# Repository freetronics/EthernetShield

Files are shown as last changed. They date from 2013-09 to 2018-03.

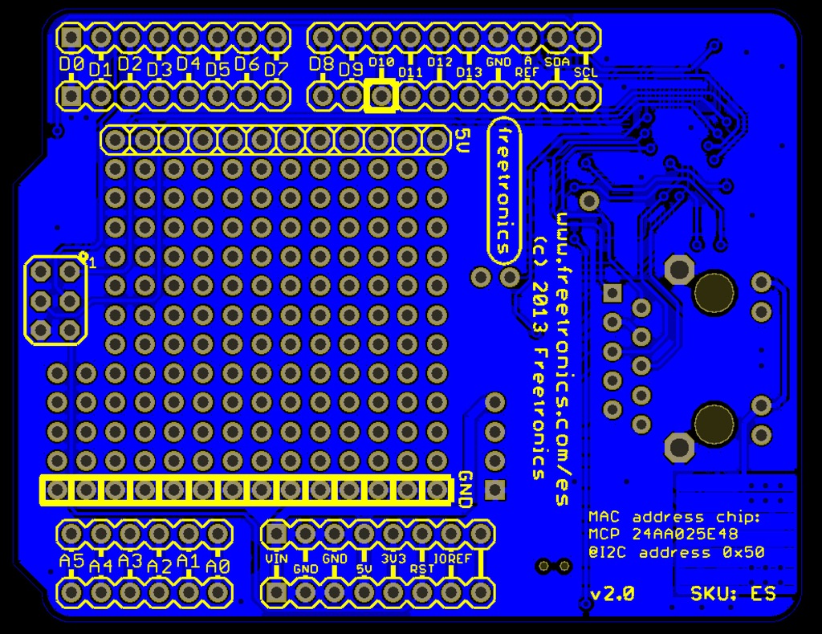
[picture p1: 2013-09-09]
docs/EthernetShield-pcb-bottom.jpg

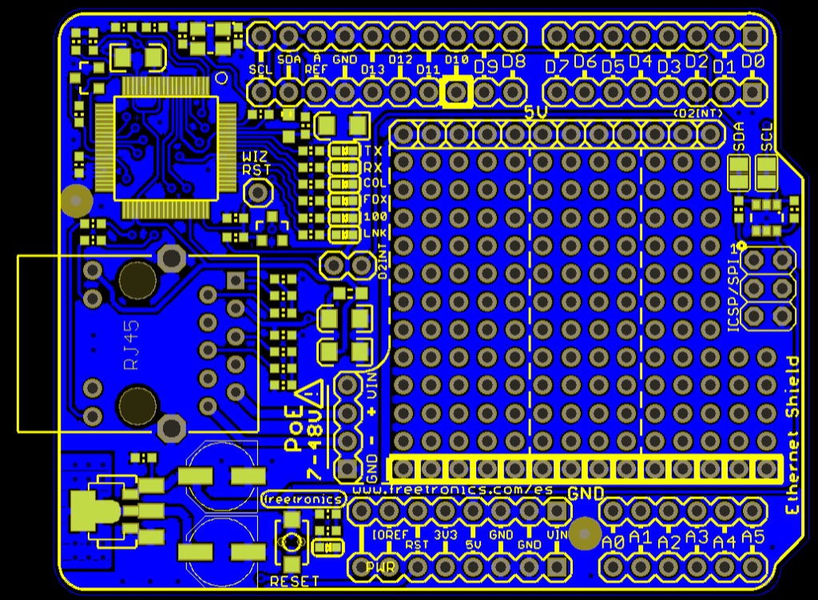
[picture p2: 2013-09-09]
docs/EthernetShield-pcb-top.jpg

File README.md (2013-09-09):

Freetronics Ethernet Shield
===========================
Copyright 2010-2012 Freetronics Pty Ltd  
Freetronics site:  www.freetronics.com  
Freetronics email: info@freetronics.com  

10/100base-T Ethernet shield for the Freetronics Eleven, Arduino Uno,
and other boards compatible with the R3 header format.

Includes significant prototyping area using the spare shield area, and
supports Power-over-Ethernet (PoE) using either simple jumpers for DIY
PoE or a daughter-board module for full standards-compliant PoE.

Features:

 * Prototyping area.
 * 10/100Base-T connectivity.
 * Power-over-Ethernet "PD" (powered device) support.
 * Activity / status indicators.
 * Reset button wired through to Arduino reset pin.
 * Wiznet W5100 IC reset circuit.
 * SPI bus contention fixed for W5100 IC.
 * Parts overlay on both the top and the bottom.

More information is available on our product page at:

  http://www.freetronics.com/ethernet

The "docs" folder within this repository includes a handy copy of the
schematic in PDF format and image(s) of the pcb.

INSTALLATION
------------
The design is saved as an EAGLE project. EAGLE PCB design software is
available from www.cadsoftusa.com free for non-commercial use. To use
this project download it and place the directory containing these files
into the "eagle" directory on your computer. Then open EAGLE and
navigate to Projects -> eagle -> EthernetShieldR3.

DISTRIBUTION
------------
The specific terms of distribution of this project are governed by the
license referenced below.

LICENSE
-------
Licensed under the TAPR Open Hardware License (www.tapr.org/OHL).
The "license" folder within this repository also contains a copy of
this license in plain text format.

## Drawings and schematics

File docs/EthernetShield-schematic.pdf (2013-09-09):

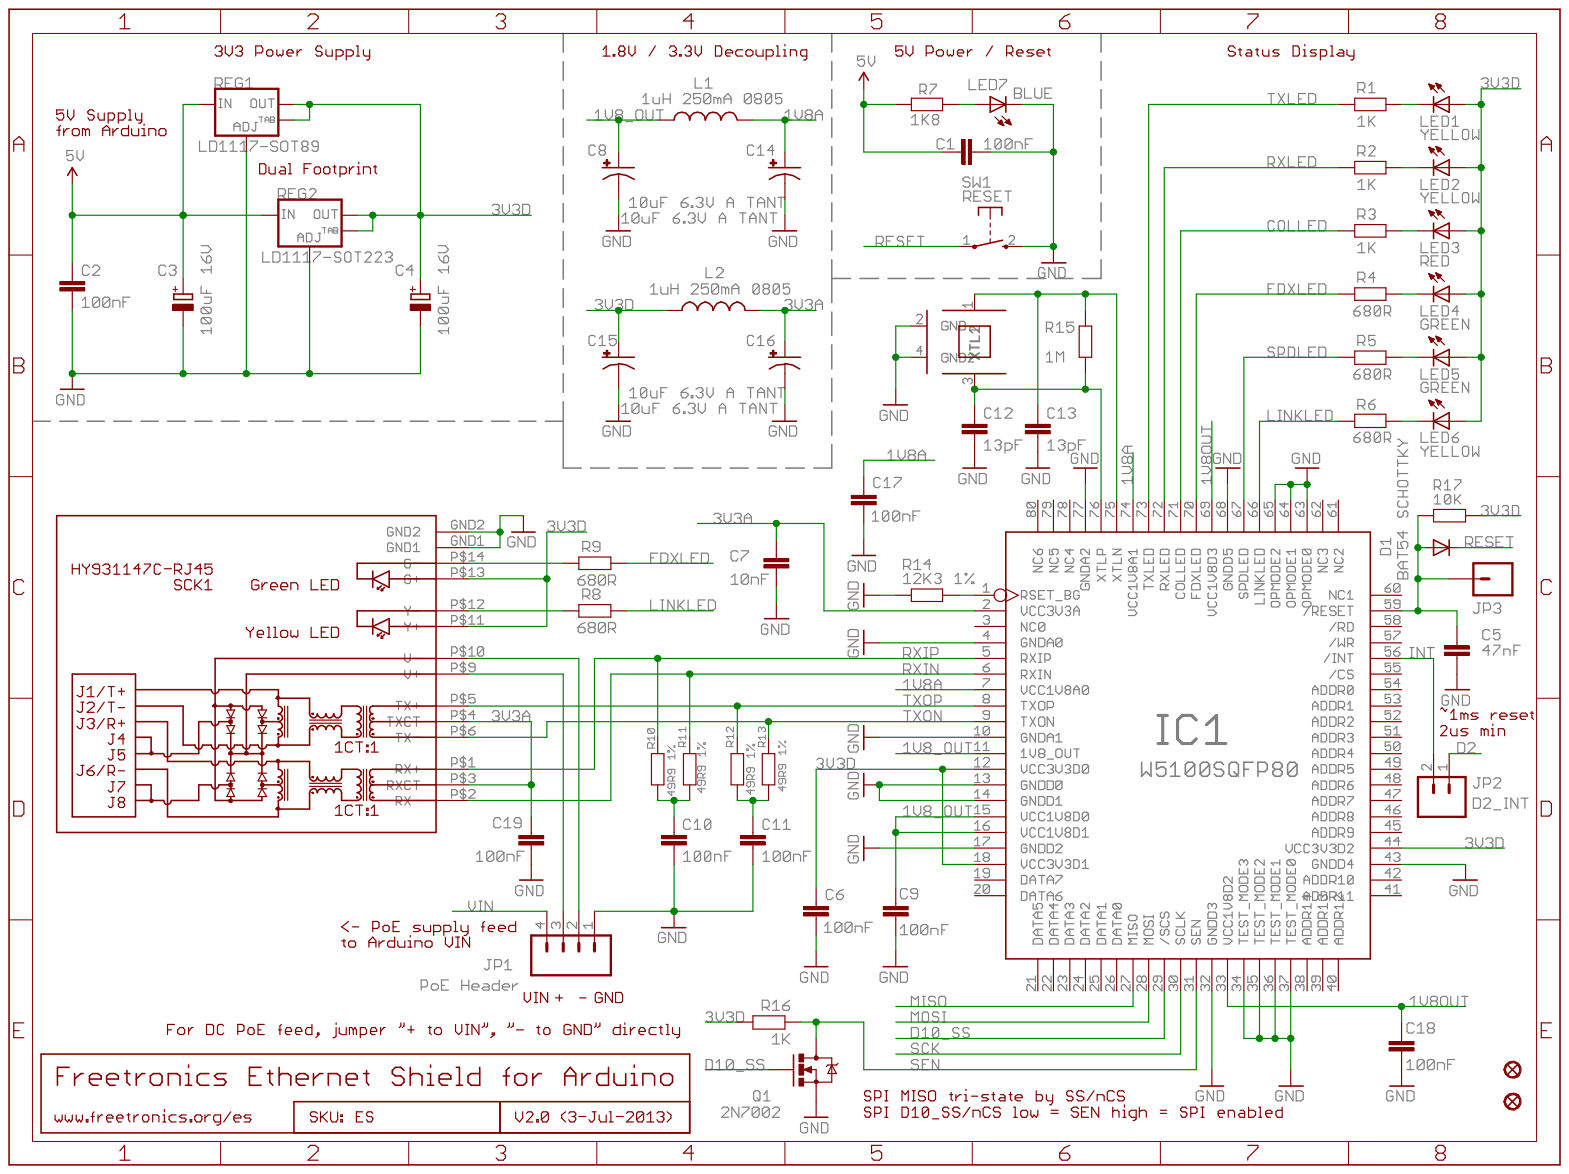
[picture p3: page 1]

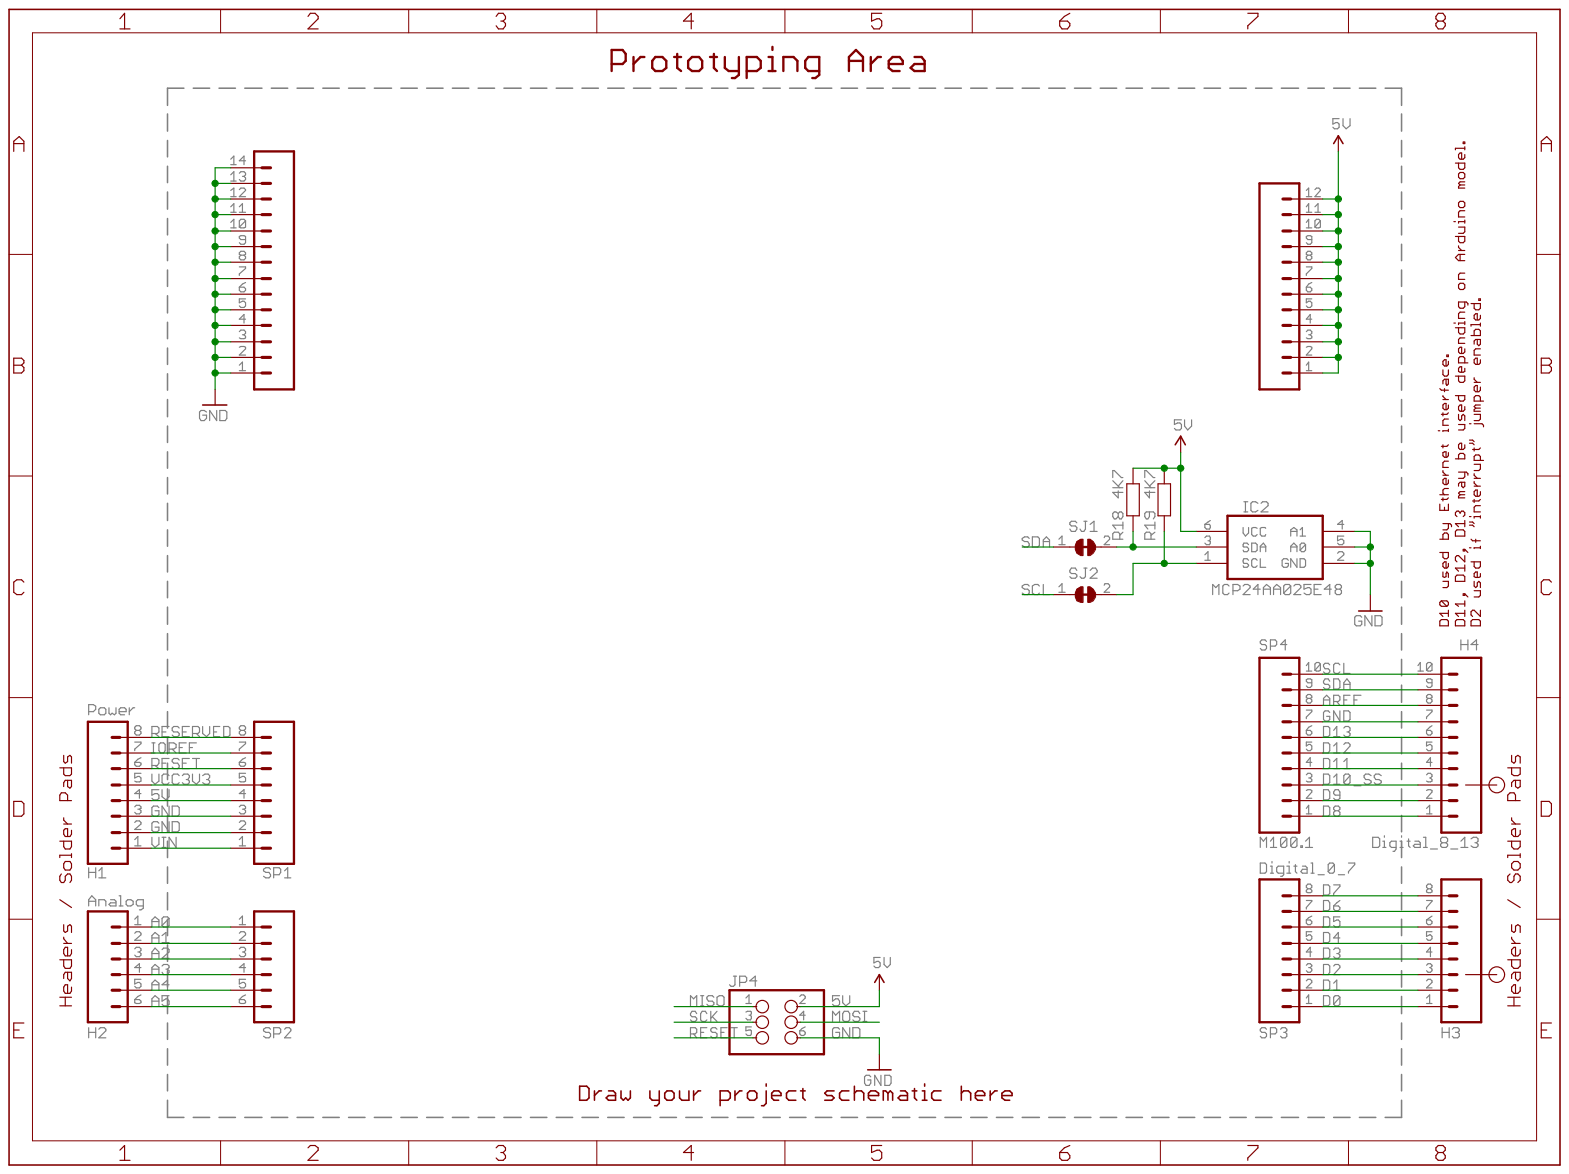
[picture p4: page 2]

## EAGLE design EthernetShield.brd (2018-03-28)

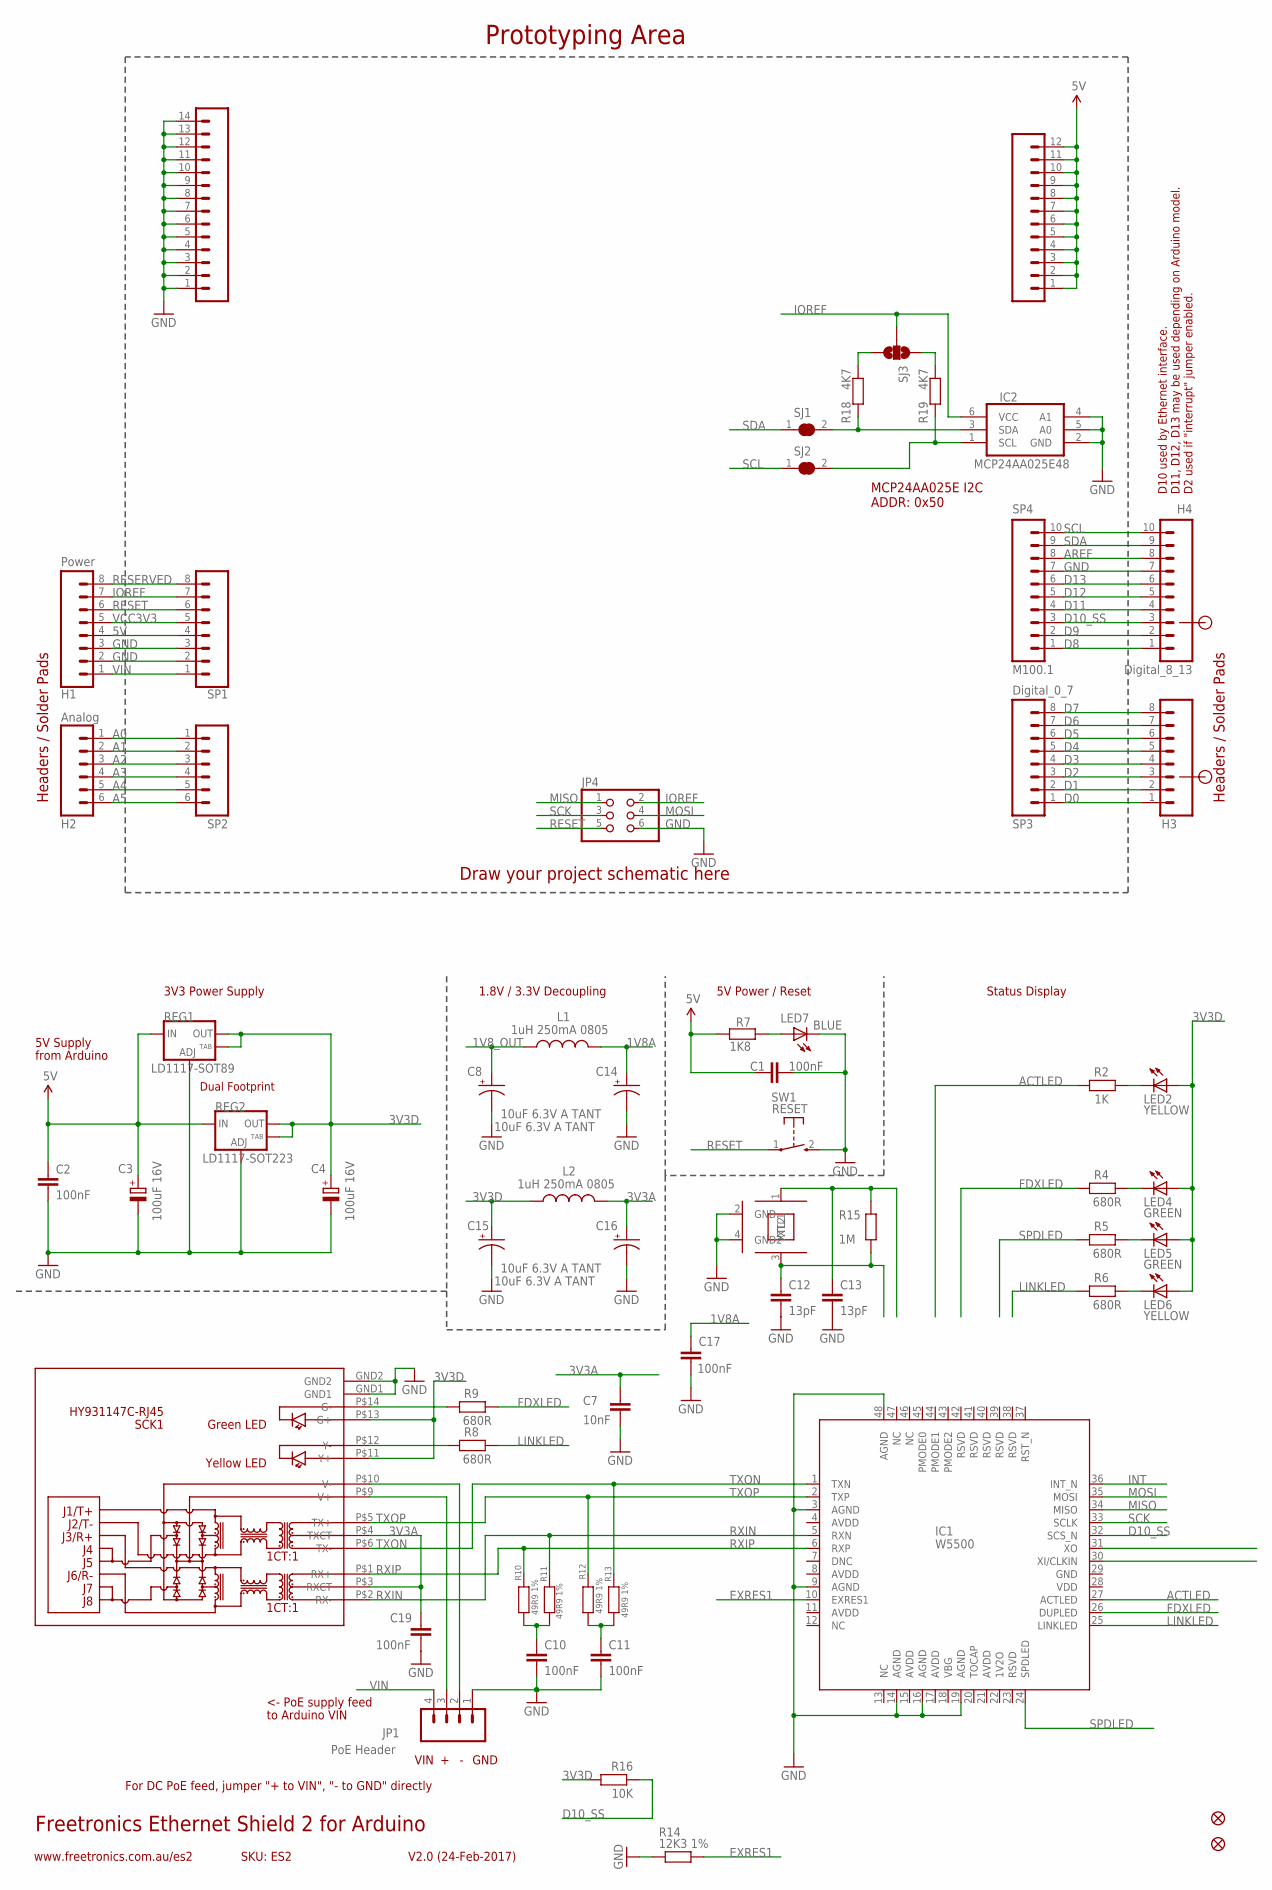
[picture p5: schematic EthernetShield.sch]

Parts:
C1, C2, C10, C11, C17, C19: 100nF; 0603
C3, C4: 100uF 16V; PANASONIC_D
C7: 10nF; 0603
C8, C14, C15, C16: 10uF 6.3V A TANT; EIA3216
C12, C13: 13pF; 0603
H1: Power; 1X08
H2: Analog; 1X06
H3: Digital_0_7; 1X08
H4: Digital_8_13; 1X10
IC1: W5500
IC2: MCP24AA025E48; SOT23-6
JP1: PoE Header; 1X04
JP4: PINHD-2X3; 2X03
L1, L2: 1uH 250mA 0805; L2012C
LED2, LED6: YELLOW; LED-0603
LED4, LED5: GREEN; LED-0603
LED7: BLUE; LED-0603
PADS_5V: M12PTH; 1X12
PADS_GND: M14; 1X14
R2: 1K; 0603
R4, R5, R6, R8, R9: 680R; 0603
R7: 1K8; 0603
R10, R11, R12, R13: 49R9 1%; 0603
R14: 12K3 1%; 0603
R15: 1M; 0603
R16: 10K; 0603
R18, R19: 4K7; 0603
REG1: LD1117-SOT89; SOT89
REG2: LD1117-SOT223; SOT223
SCK1: HY931147C-RJ45; HY931147C
SJ1, SJ2: SJCN; SJC
SJ3: SOLDERJUMPER_2WAYT; SJ_2
SP1: M08; 1X08
SP2: Analog; 1X06
SP3: Digital_0_7; 1X08
SP4: M100.1; 1X10
SW1: RESET; TACTILE_SWITCH_SMD_2PIN_TINY
U$6, U$8: FIDUCIAL1X2.5; FIDUCIAL-1X2.5
XTL1: 25MHZ; CRYSTAL-SMD-3X2

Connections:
1V8A: C14.A (+), C17.1, L1.2
1V8_OUT: C8.A (+), L1.1
3V3A: C7.1, C16.A (+), C19.1, L2.2, SCK1.P$3 (RXCT), SCK1.P$4 (TXCT)
3V3D: C4.+, C15.A (+), L2.1, LED2.A, LED4.A, LED5.A, LED6.A, R16.2, REG1.2 (OUT), REG1.4 (OUT), REG2.2 (OUT), REG2.4 (OUT), SCK1.P$11 (Y+), SCK1.P$13 (G+)
5V: C1.1, C2.1, C3.+, H1.4, PADS_5V.1, PADS_5V.2, PADS_5V.3, PADS_5V.4, PADS_5V.5, PADS_5V.6, PADS_5V.7, PADS_5V.8, PADS_5V.9, PADS_5V.10, PADS_5V.11, PADS_5V.12, R7.1, REG1.3 (IN), REG2.3 (IN), SP1.4
A0: H2.1, SP2.1
A1: H2.2, SP2.2
A2: H2.3, SP2.3
A3: H2.4, SP2.4
A4: H2.5, SP2.5
A5: H2.6, SP2.6
ACTLED: IC1.27 (ACTLED), R2.2
AREF: H4.8, SP4.8
D0: H3.1, SP3.1
D1: H3.2, SP3.2
D2: H3.3, SP3.3
D3: H3.4, SP3.4
D4: H3.5, SP3.5
D5: H3.6, SP3.6
D6: H3.7, SP3.7
D7: H3.8, SP3.8
D8: H4.1, SP4.1
D9: H4.2, SP4.2
D10_SS: H4.3, IC1.32 (SCS_N), R16.1, SP4.3
D11: H4.4, SP4.4
D12: H4.5, SP4.5
D13: H4.6, SP4.6
EXRES1: IC1.10 (EXRES1), R14.2
FDXLED: IC1.26 (DUPLED), R4.2, R9.1
GND: C1.2, C2.2, C3.-, C4.-, C7.2, C8.C (-), C10.2, C11.2, C12.2, C13.2, C14.C (-), C15.C (-), C16.C (-), C17.2, C19.2, H1.2, H1.3, H4.7, IC1.3 (AGND), IC1.9 (AGND), IC1.14 (AGND), IC1.16 (AGND), IC1.19 (AGND), IC1.48 (AGND), IC2.2 (GND), IC2.4 (A1), IC2.5 (A0), JP1.1, JP4.6, LED7.C, PADS_GND.1, PADS_GND.2, PADS_GND.3, PADS_GND.4, PADS_GND.5, PADS_GND.6, PADS_GND.7, PADS_GND.8, PADS_GND.9, PADS_GND.10, PADS_GND.11, PADS_GND.12, PADS_GND.13, PADS_GND.14, R14.1, REG1.1 (ADJ), REG2.1 (ADJ), SCK1.GND1, SCK1.GND2, SP1.2, SP1.3, SP4.7, SW1.2 (S), XTL1.2 (GND), XTL1.4 (GND2)
INT: IC1.36 (INT_N)
IOREF: H1.7, IC2.6 (VCC), JP4.2, SJ3.2, SP1.7
LINKLED: IC1.25 (LINKLED), R6.2, R8.1
MISO: IC1.34 (MISO), JP4.1
MOSI: IC1.35 (MOSI), JP4.4
unnamed: C11.1, R12.1, R13.2
unnamed: IC2.1 (SCL), R19.2, SJ2.2
unnamed: IC2.3 (SDA), R18.2, SJ1.2
unnamed: R18.1, SJ3.3
unnamed: R19.1, SJ3.1
unnamed: R9.2, SCK1.P$14 (G-)
unnamed: JP1.3, SCK1.P$9 (V+)
unnamed: JP1.2, SCK1.P$10 (V-)
unnamed: LED7.A, R7.2
unnamed: C10.1, R10.1, R11.2
unnamed: LED5.C, R5.1
unnamed: LED6.C, R6.1
unnamed: LED4.C, R4.1
unnamed: LED2.C, R2.1
unnamed: R8.2, SCK1.P$12 (Y-)
RESERVED: H1.8, SP1.8
RESET: H1.6, JP4.5, SP1.6, SW1.1
RXIN: IC1.5 (RXN), R11.1, SCK1.P$2 (RX-)
RXIP: IC1.6 (RXP), R10.2, SCK1.P$1 (RX+)
SCK: IC1.33 (SCLK), JP4.3
SCL: H4.10, SJ2.1, SP4.10
SDA: H4.9, SJ1.1, SP4.9
SPDLED: IC1.24 (SPDLED), R5.2
TXON: IC1.1 (TXN), R13.1, SCK1.P$6 (TX-)
TXOP: IC1.2 (TXP), R12.2, SCK1.P$5 (TX+)
VCC3V3: H1.5, SP1.5
VIN: H1.1, JP1.4, SP1.1
XTLN: C13.1, R15.2, XTL1.1 (XTL1)
XTLP: C12.1, R15.1, XTL1.3 (XTL2)

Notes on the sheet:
Prototyping Area
Freetronics Ethernet Shield 2 for Arduino
V2.0 (24-Feb-2017)
www.freetronics.com.au/es2
SKU: ES2
3V3 Power Supply
Status Display
5V Power / Reset
Headers / Solder Pads
Dual Footprint
from Arduino
1.8V / 3.3V Decoupling
Draw your project schematic here
D10 used by Ethernet interface.
D2 used if "interrupt" jumper enabled.
VIN
GND
<- PoE supply feed
5V Supply
For DC PoE feed, jumper "+ to VIN", "- to GND" directly
to Arduino VIN
D11, D12, D13 may be used depending on Arduino model.
MCP24AA025E I2C ADDR: 0x50

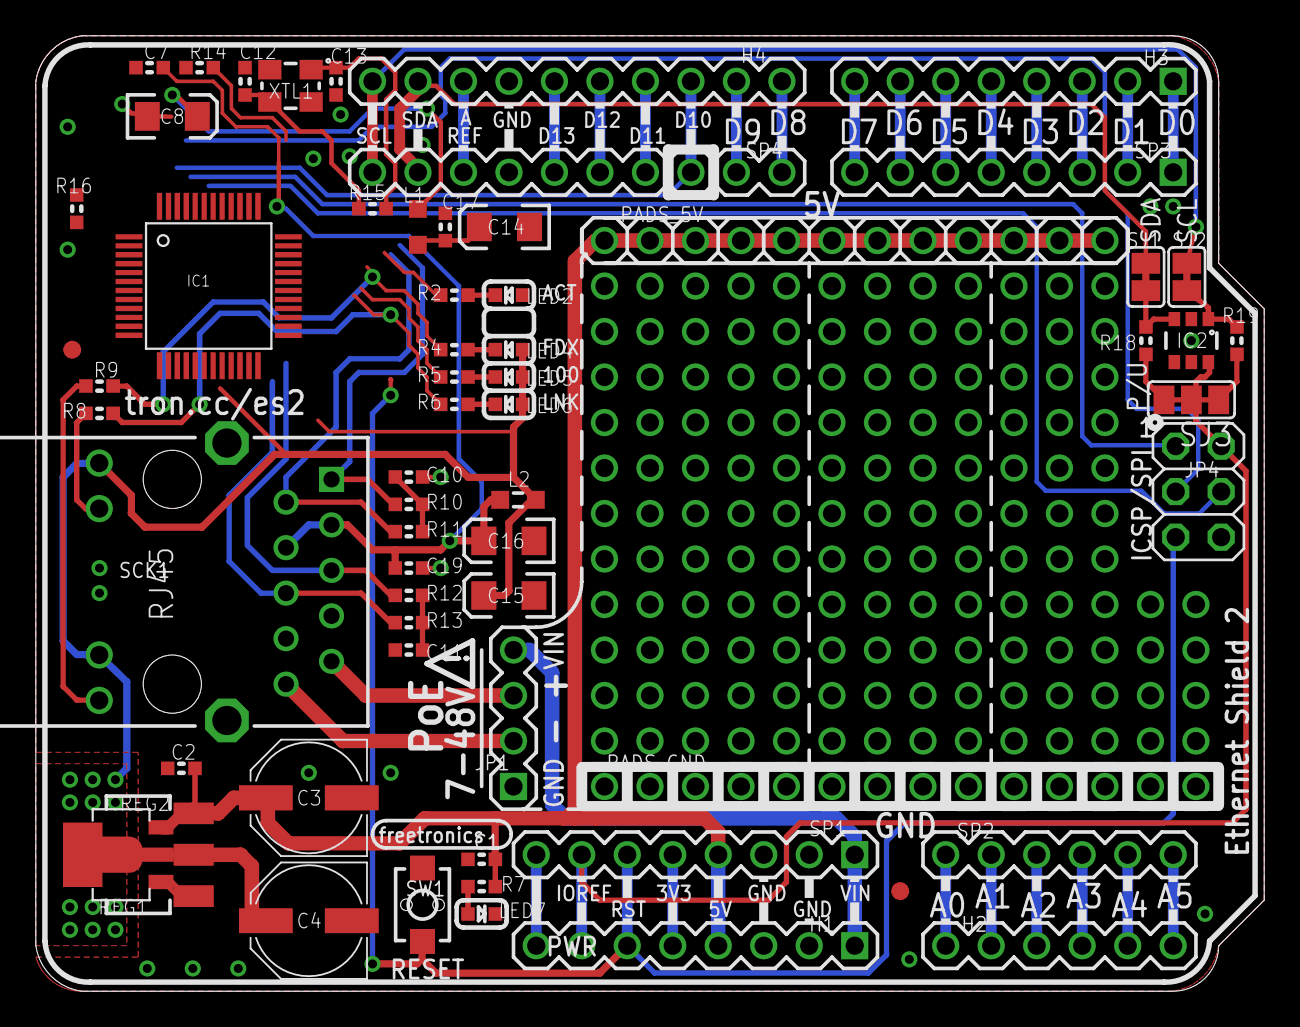
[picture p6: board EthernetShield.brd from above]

Board: 2 copper layers, 68.6 x 53.3 mm, 62 parts (0 on the bottom side), 63 nets.

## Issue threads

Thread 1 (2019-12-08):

Source IP Address is lost, changes to 0.0.0.0

sgreadly, 2019-12-08:
Hi,

I've got the EtherTen Arduino, and noticed the past few months that quite often the Ethernet connection fails - I notice an error or connection failure via Serial output. I can't find a specific trigger..

* If you slightly touch/move it, it can trigger this
* If you leave it as-is, after a few hours, or day or so, it can also fail.

That said, you can leave it running for several days without an issue..

Hitting the Reset button often fixes it, though sometimes you have to hit the button several times, and/or start fiddling around a bit..

Running a packet capture, I noticed interestingly that it seems to drop the IP Address for some reason, replacing it with 0.0.0.0

# tshark -r pc.pcap
    1   0.000000      **0.0.0.0** → 192.168.1.4  TCP 58 49291 → 80 [SYN] Seq=0 Win=2048 Len=0 MSS=1460
    2   0.202147      **0.0.0.0** → 192.168.1.4  TCP 58 [TCP Retransmission] 49291 → 80 [SYN] Seq=0 Win=2048 Len=0 MSS=1460
    3   0.606498      **0.0.0.0** → 192.168.1.4  TCP 58 [TCP Retransmission] 49291 → 80 [SYN] Seq=0 Win=2048 Len=0 MSS=1460
    4   2.165710      **0.0.0.0** → 192.168.1.4  TCP 58 49292 → 80 [SYN] Seq=0 Win=2048 Len=0 MSS=1460
    5   2.368013      **0.0.0.0** → 192.168.1.4  TCP 58 [TCP Retransmission] 49292 → 80 [SYN] Seq=0 Win=2048 Len=0 MSS=1460
    6   2.772296      **0.0.0.0** → 192.168.1.4  TCP 58 [TCP Retransmission] 49292 → 80 [SYN] Seq=0 Win=2048 Len=0 MSS=1460

# tshark -r pc.pcap -Y "frame.number==1" -PV

 > 0.000000      **0.0.0.0** → 192.168.1.4  TCP 58 49291 → 80 [SYN] Seq=0 Win=2048 Len=0 MSS=1460
 Frame 1: 58 bytes on wire (464 bits), 58 bytes captured (464 bits)
    Encapsulation type: Ethernet (1)
    Arrival Time: Dec  9, 2019 08:21:54.688585000 NZDT
    [Time shift for this packet: 0.000000000 seconds]
    Epoch Time: 1575832914.688585000 seconds
    [Time delta from previous captured frame: 0.000000000 seconds]
    [Time delta from previous displayed frame: 0.000000000 seconds]
    [Time since reference or first frame: 0.000000000 seconds]
    Frame Number: 1
    Frame Length: 58 bytes (464 bits)
    Capture Length: 58 bytes (464 bits)
    [Frame is marked: False]
    [Frame is ignored: False]
    [Protocols in frame: eth:ethertype:ip:tcp]
Ethernet II, Src: 00:00:00_00:00:00 (00:00:00:00:00:00), Dst: Raspberr_22:09:02 (b8:27:eb:22:09:02)
    Destination: Raspberr_22:09:02 (b8:27:eb:22:09:02)
        Address: Raspberr_22:09:02 (b8:27:eb:22:09:02)
        .... ..0. .... .... .... .... = LG bit: Globally unique address (factory default)
        .... ...0 .... .... .... .... = IG bit: Individual address (unicast)
    Source: 00:00:00_00:00:00 (00:00:00:00:00:00)
        Address: 00:00:00_00:00:00 (00:00:00:00:00:00)
        .... ..0. .... .... .... .... = LG bit: Globally unique address (factory default)
        .... ...0 .... .... .... .... = IG bit: Individual address (unicast)
    Type: IPv4 (0x0800)
Internet Protocol Version 4, Src: 0.0.0.0, Dst: 192.168.1.4
    0100 .... = Version: 4
    .... 0101 = Header Length: 20 bytes (5)
    Differentiated Services Field: 0x00 (DSCP: CS0, ECN: Not-ECT)
        0000 00.. = Differentiated Services Codepoint: Default (0)
        .... ..00 = Explicit Congestion Notification: Not ECN-Capable Transport (0)
    Total Length: 44
    Identification: 0x0011 (17)
    Flags: 0x4000, Don't fragment
        0... .... .... .... = Reserved bit: Not set
        .1.. .... .... .... = Don't fragment: Set
        ..0. .... .... .... = More fragments: Not set
        ...0 0000 0000 0000 = Fragment offset: 0
    Time to live: 128
    Protocol: TCP (6)
    Header checksum: 0x390f [validation disabled]
    [Header checksum status: Unverified]
    **Source: 0.0.0.0**
    Destination: 192.168.1.4
Transmission Control Protocol, Src Port: 49291, Dst Port: 80, Seq: 0, Len: 0
    Source Port: 49291
    Destination Port: 80
    [Stream index: 0]
    [TCP Segment Len: 0]
    Sequence number: 0    (relative sequence number)
    [Next sequence number: 0    (relative sequence number)]
    Acknowledgment number: 0
    0110 .... = Header Length: 24 bytes (6)
    Flags: 0x002 (SYN)
        000. .... .... = Reserved: Not set
        ...0 .... .... = Nonce: Not set
        .... 0... .... = Congestion Window Reduced (CWR): Not set
        .... .0.. .... = ECN-Echo: Not set
        .... ..0. .... = Urgent: Not set
        .... ...0 .... = Acknowledgment: Not set
        .... .... 0... = Push: Not set
        .... .... .0.. = Reset: Not set
        .... .... ..1. = Syn: Set
            [Expert Info (Chat/Sequence): Connection establish request (SYN): server port 80]
                [Connection establish request (SYN): server port 80]
                [Severity level: Chat]
                [Group: Sequence]
        .... .... ...0 = Fin: Not set
        [TCP Flags: ··········S·]
    Window size value: 2048
    [Calculated window size: 2048]
    Checksum: 0xc75c [unverified]
    [Checksum Status: Unverified]
    Urgent pointer: 0
    Options: (4 bytes), Maximum segment size
        TCP Option - Maximum segment size: 1460 bytes
            Kind: Maximum Segment Size (2)
            Length: 4
            MSS Value: 1460
    [Timestamps]
        [Time since first frame in this TCP stream: 0.000000000 seconds]
        [Time since previous frame in this TCP stream: 0.000000000 seconds]

Naturally, the server drops such packets.

I couldn't find any reason to why it would forget its IP Address and replace with 0.0.0.0.. I'm happy to provide more data - let me know what you need.

I'm using

* Arduino AVR Boards by Arduino v1.8.2 (aka. Arduino Ethernet).
* IP Address is obtained via DHCP - not sure if that makes any difference.

Note, this is 1 of 2 failures I've witnessed, where the second one is more serious - total failure without any packets egressing the Arduino.

The second more serious failure, seems to be stuck at this stage:

```
Ethernet.begin(mac);

  if (Ethernet.begin(mac) == 0) {

    Serial.println("Failed to configure Ethernet using DHCP");
    lcd.setCursor(0,1);
    lcd.print("DHCP Failed :(");

    // Check for Ethernet hardware present
    if (Ethernet.hardwareStatus() == EthernetNoHardware) {
      Serial.println("Ethernet shield was not found.  Sorry, can't run without hardware. :(");
<snip>
```

Output:

> Initialise ethernet via DHCP... Failed to configure Ethernet using DHCP
> Ethernet shield was not found.  Sorry, can't run without hardware. :(

Listening on port 67 or port 68, I don't see anything out.. meaning the Arduino isn't firing out a DHCP Discovery packet..

Ta.

sgreadly, 2020-12-22:
Clearly after a year of silence and no responses to the email requests I sent via your website, you've shown that you do not care about your customers, and that this project is dead in its water. I chucked the EtherTen in the bin and went for another brand.

Closing off.

Closed 2020-12-22.

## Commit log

2010-04-27 Added initial version of Eagle files
    [EthernetShield.brd, EthernetShield.sch]
2010-04-28 Minor routing tweaks and start of restructuring schematic
    [EthernetShield.brd, EthernetShield.sch]
2010-04-29 The "It gets worse before it gets better" release! * Major restructuring of schematic to explicitly show connections rather than relying on net labels. * Switched INT solder header to a proper 2-pin 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
    [EthernetShield.brd, EthernetShield.sch]
2010-04-29 Moved major schematic sections around trying to make a logical layout
    [EthernetShield.sch]
2010-04-30 The "slightly less tragic than last time" release! * Major re-routing around top of IC to make things neater and use less vias. * Added fiducial markers for assembly bots. * Minor track moves to avoi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
    [EthernetShield.brd, EthernetShield.sch]
2010-04-30 Tiny track tweak
    [EthernetShield.brd]
2010-04-30 Labelling tweaks
    [EthernetShield.brd, EthernetShield.sch]
2010-04-30 Swapped several parts for custom library parts to improve footprints and symbols
    [EthernetShield.brd, EthernetShield.sch]
2010-04-30 Replaced SOT89 variant of LD1117 with custom library part to improve footprint
    [EthernetShield.brd, EthernetShield.sch]
2010-05-01 Replaced more parts with custom library parts to optimise footprints, and adjusted routing to suit
    [EthernetShield.brd, EthernetShield.sch]
2010-05-06 Minor routing and schematic layout tweaks
    [EthernetShield.brd, EthernetShield.sch]
2010-05-09 Adjusted LED dropper resistor values to balance brightness
    [EthernetShield.brd, EthernetShield.sch]
2010-05-20 Renamed and numbered all parts sequentially
    [EthernetShield.brd, EthernetShield.sch]
2010-05-21 Switched to Hanrun magjack so we can add PoE support
    [EthernetShield.sch]
2010-05-21 Start of routing for Hanrun magjack, totally busted right now
    [EthernetShield.brd]
2010-05-22 More routing. Very ugly and busted right now
    [EthernetShield.brd]
2010-05-23 Finally got it routing OK. Still needs cleanup
    [EthernetShield.brd, EthernetShield.sch]
2010-05-24 Updated PoE size on overlay
    [EthernetShield.brd]
2010-05-24 Trivial routing tweak
    [EthernetShield.brd]
2010-05-28 Trivial track angle tweaks
    [EthernetShield.brd]
2010-06-01 Repositioned LEDs; added border to LEDs; tweaked PoE markings
    [EthernetShield.brd]
2010-06-01 Updated part designators; tweaked track routing
    [EthernetShield.brd, EthernetShield.sch]
2010-06-02 Restructured schematic into 2 virtual sheets to allow space for a template worksheet
    [EthernetShield.brd, EthernetShield.sch]
2010-06-03 Improved layout around prototyping area and marked pins in use
    [EthernetShield.sch]
2010-06-03 Minor routing tweaks
    [EthernetShield.brd]
2010-06-03 The tiniest track tweak in the history of tweaks. But it mattered. Really. In some universe, at least.
    [EthernetShield.brd]
2010-06-16 1V8 and 3V3 filter system, power feed revisions
    [EthernetShield.brd, EthernetShield.sch]
2010-06-16 small mods, SEN and RESET control next
    [EthernetShield.sch]
2010-06-17 SEN SPI fix and WIZRST auto/manual W5100 reset
    [EthernetShield.brd, EthernetShield.sch]
2010-06-21 PCB layout rearrangement to suit - still routing
    [EthernetShield.brd, EthernetShield.sch]
2010-06-27 Schematic ERC fixes, PCB rework
    [EthernetShield.brd, EthernetShield.sch]
2010-06-27 PCB track connectivity complete, GND review pending
    [EthernetShield.brd]
2010-06-28 Last few checks
    [EthernetShield.brd, EthernetShield.sch]
2010-06-28 Footprint revisions
    [EthernetShield.brd, EthernetShield.sch]
2010-06-29 Production Release
    [EthernetShield.brd, EthernetShield.sch]
2010-06-29 Bottom overlay went to last minute tweak-town
    [EthernetShield.brd]
2010-07-31 ES v1_1 full production release
    [EthernetShield.brd, EthernetShield.sch]
2010-08-20 ES V1_1 production release (final - C5 47nF)
    [EthernetShield.brd, EthernetShield.sch]
2013-09-09 Upgrade to R3 headers and add MAC address chip
    [EthernetShield.brd, EthernetShield.sch]
2013-09-09 Updates for release v2.0
    [EthernetShield.brd, EthernetShield.sch]
2014-08-03 Changed I2C pull-ups to use IOREF, and added isolation jumpers
    [EthernetShield.brd, EthernetShield.sch]
2014-08-03 Added info about I2C address
    [EthernetShield.brd, EthernetShield.sch]
2018-03-28 Began replacing W5100 with W5500
    [EthernetShield.brd, EthernetShield.sch]

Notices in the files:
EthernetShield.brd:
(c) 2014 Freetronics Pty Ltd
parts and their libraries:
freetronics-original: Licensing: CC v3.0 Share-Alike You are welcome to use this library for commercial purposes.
